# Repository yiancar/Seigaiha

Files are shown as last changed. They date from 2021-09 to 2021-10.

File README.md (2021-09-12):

Seigaiha
================

seigaiha

This Alice layout keyboard kit is made using ONLY through hole components and inspired by the [Plaid](https://github.com/hsgw/plaid) and [TGR Alice](https://geekhack.org/index.php?topic=95054.0).

Atmega328p with VUSB on [QMK firmware](https://github.com/qmk/qmk_firmware).

To alter the pcb use KiCAD V5.0 or newer as it already contains most of the libraries. The additional libraries are provided.

License
===========

This project is licensed under the [Creative Commons Attribution-NonCommercial 4.0 International License](https://creativecommons.org/licenses/by-nc/4.0/).

If you have remixed, adapted or build upon this work and wish to remove the non-commercial clause for your own project please contact me at https://www.yiancar-designs.com. Your request is more than likely to be granted. The non-commercial part of the license is intended to avoid direct copies of the work to be sold for commercial gain by third parties.

The USB4085-GF-A footprint, symbol and 3D model are licensed under [Attribution-ShareAlike 4.0 International](https://creativecommons.org/licenses/by-sa/4.0/). Originally created by [SnapEDA](https://snapeda.com). The footprint has been modified to increase the hole size of the shield pads.



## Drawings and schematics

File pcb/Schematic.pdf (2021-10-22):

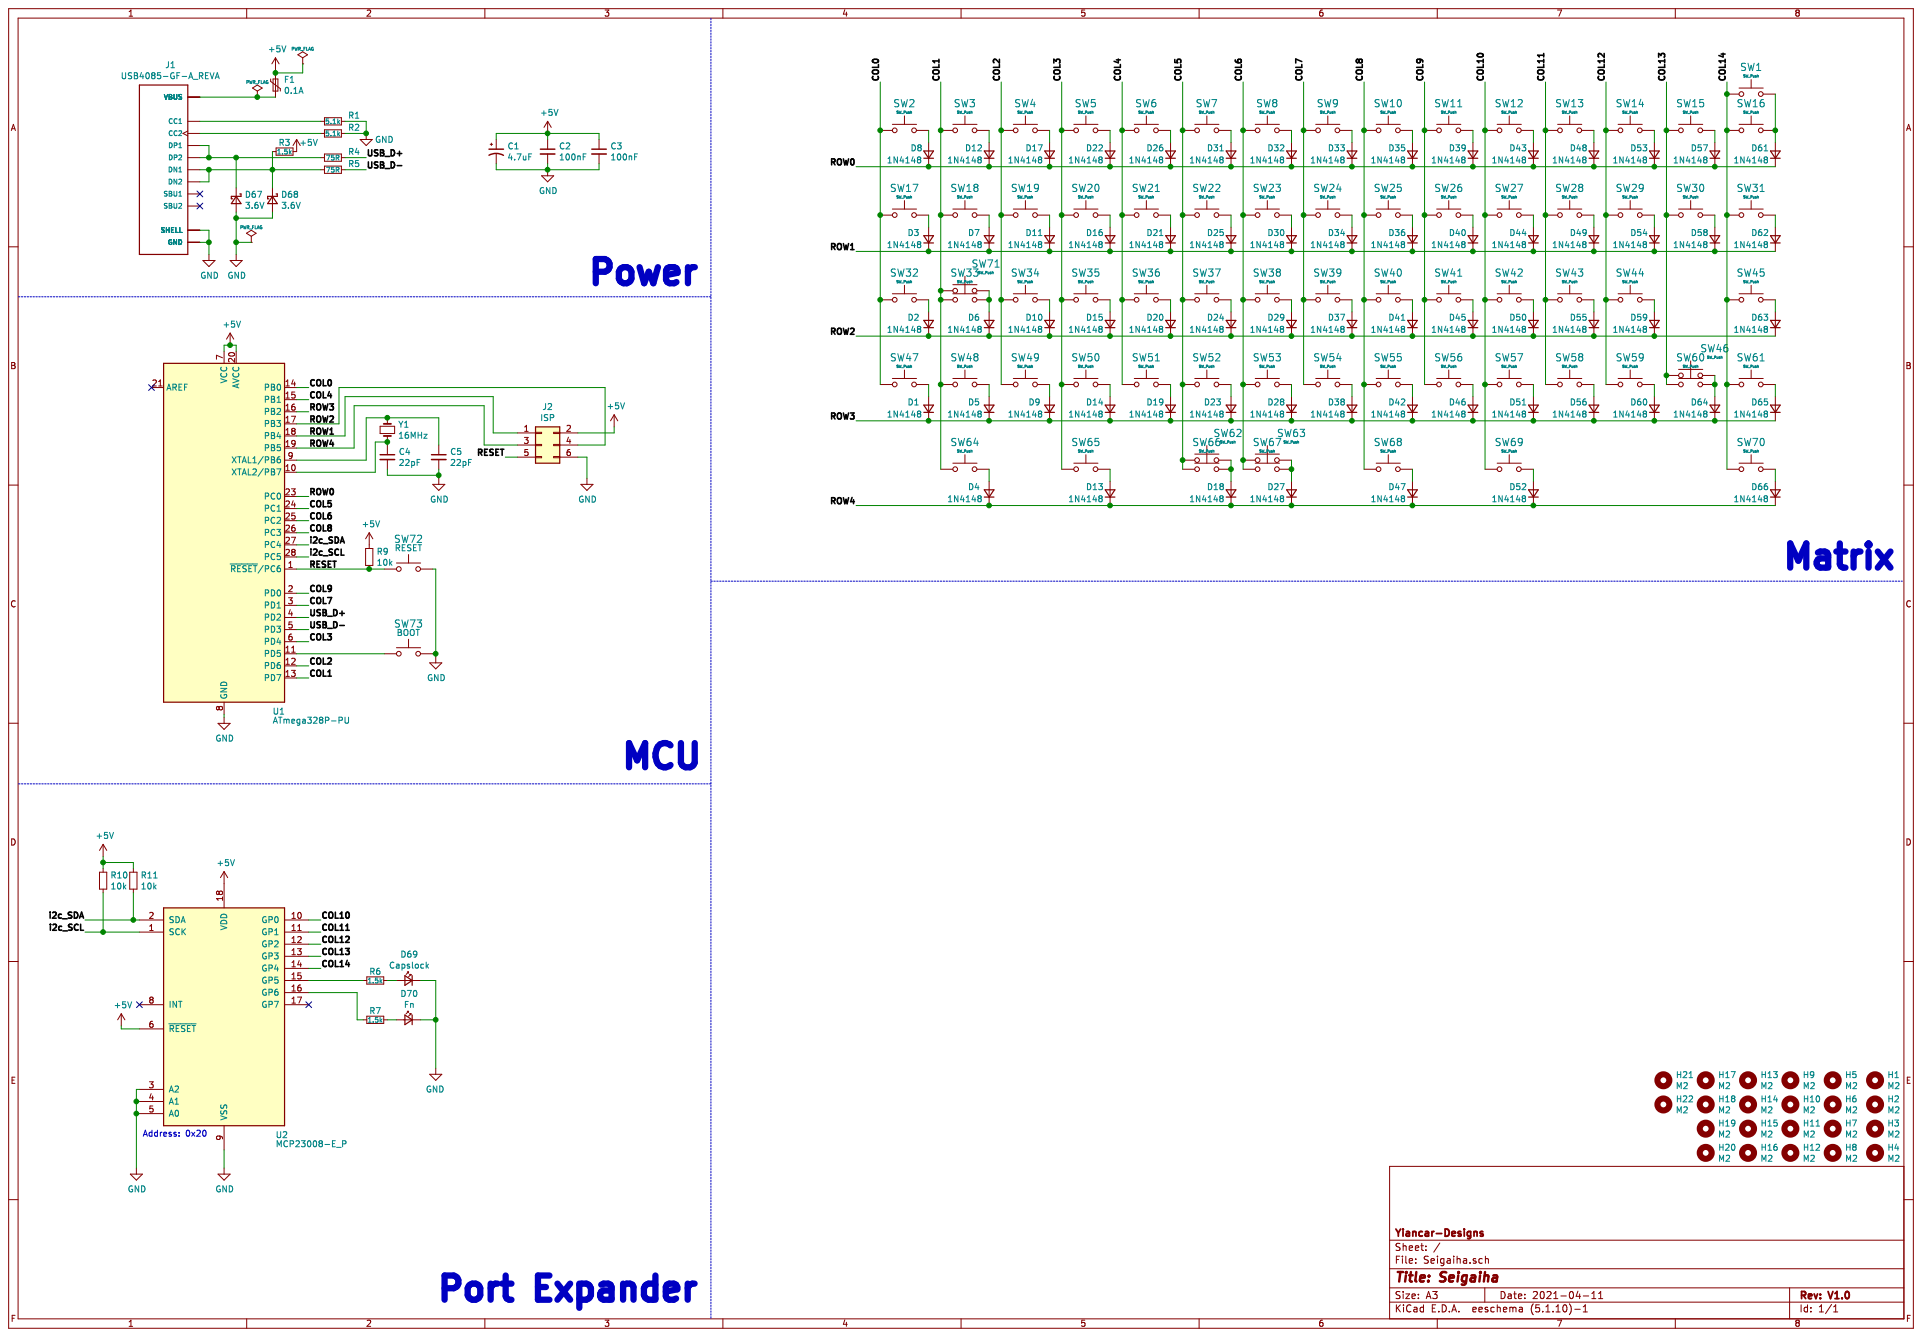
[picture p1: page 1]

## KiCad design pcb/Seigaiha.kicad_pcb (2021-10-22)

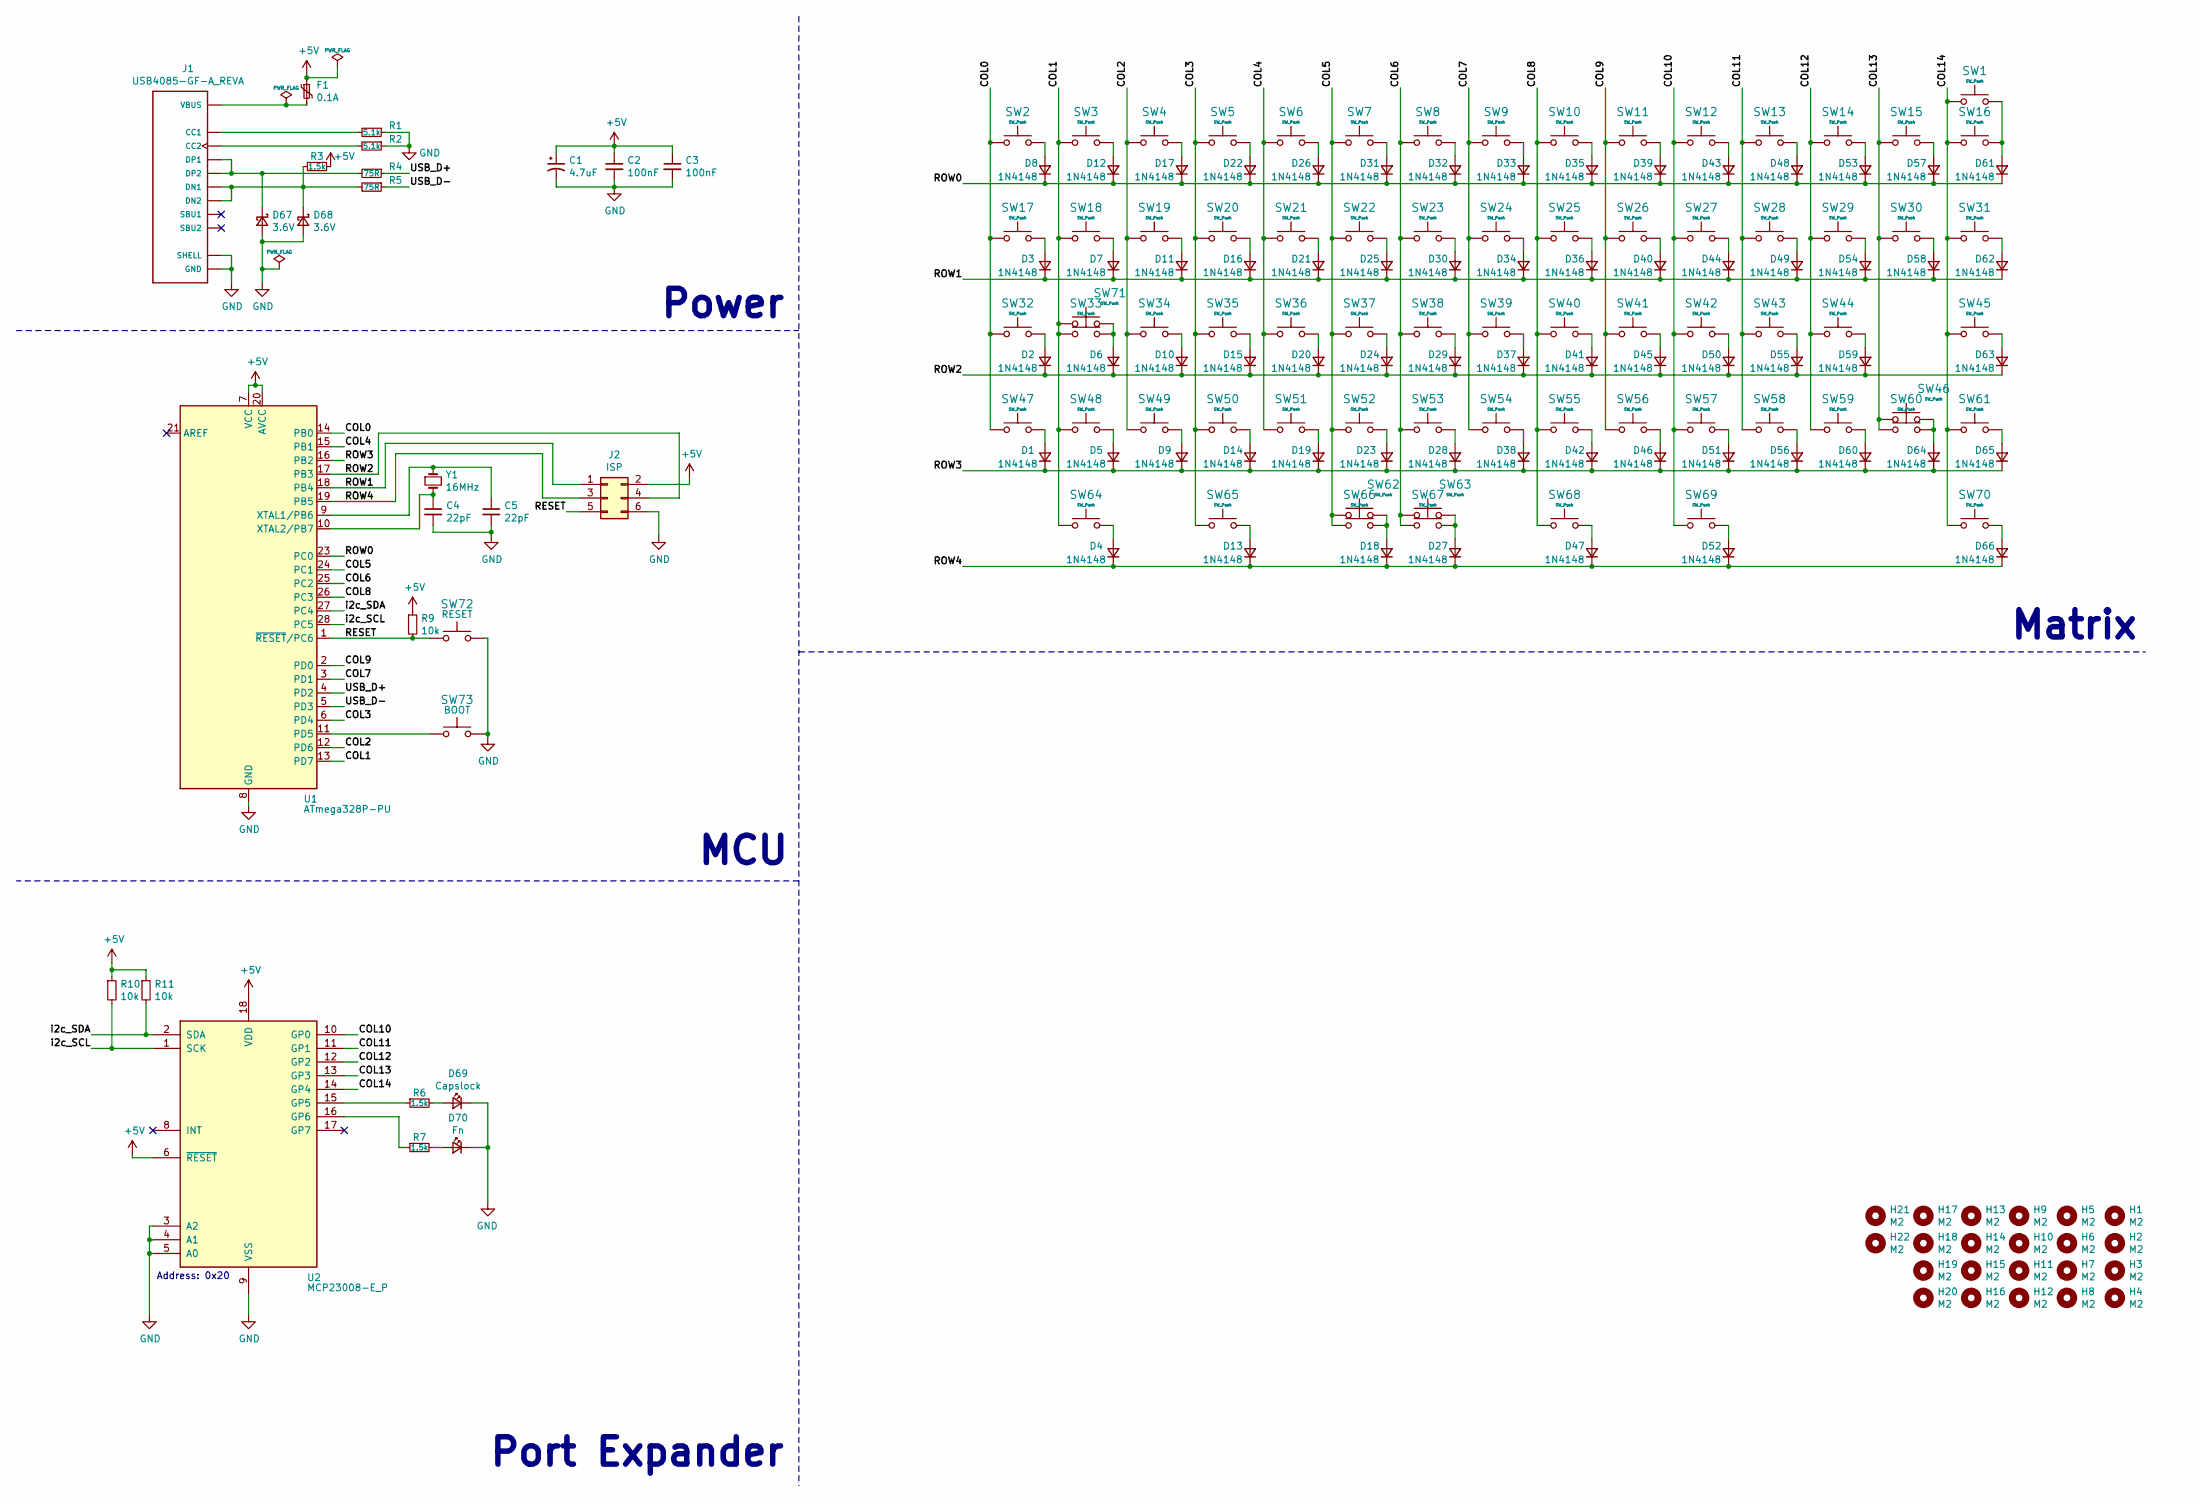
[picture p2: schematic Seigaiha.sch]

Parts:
C1: 4.7uF; CP_Radial_D4.0mm_P1.50mm
C2, C3: 100nF; C_Disc_D4.3mm_W1.9mm_P5.00mm
C4, C5: 22pF; C_Disc_D4.3mm_W1.9mm_P5.00mm
D1, D2, D3, D4, D5, D6, D7, D8, D9, D10, D11, D12, D13, D14, D15, D16, D17, D18, D19, D20, D21, D22, D23, D24, D25, D26, D27, D28, D29, D30, D31, D32, D33, D34, D35, D36, D37, D38, D39, D40, D41, D42, D43, D44, D45, D46, D47, D48, D49, D50, D51, D52, D53, D54, D55, D56, D57, D58, D59, D60, D61, D62, D63, D64, D65, D66: 1N4148; D_DO-35_SOD27_P7.62mm_Horizontal
D67, D68: 3.6V; D_DO-35_SOD27_P7.62mm_Horizontal
D69: Capslock; LED_D3.0mm_Clear
D70: Fn; LED_D3.0mm_Clear
F1: 0.1A; C_Disc_D5.0mm_W2.5mm_P5.00mm
H1, H2, H3, H4, H5, H6, H7, H8, H9, H10, H11, H12, H13, H14, H15, H16, H17, H18, H19, H20, H21, H22: M2; MountingHole_2.2mm_M2_DIN965_Pad
J1: USB4085-GF-A_REVA; GCT_USB4085-GF-A_REVA
J2: ISP; PinHeader_2x03_P2.54mm_Vertical
R1, R2: 5.1k; R_Axial_DIN0204_L3.6mm_D1.6mm_P5.08mm_Horizontal
R3, R6, R7: 1.5k; R_Axial_DIN0204_L3.6mm_D1.6mm_P5.08mm_Horizontal
R4, R5: 75R; R_Axial_DIN0204_L3.6mm_D1.6mm_P5.08mm_Horizontal
R9, R10, R11: 10k; R_Axial_DIN0204_L3.6mm_D1.6mm_P5.08mm_Horizontal
SW1, SW2, SW3, SW4, SW5, SW6, SW7, SW8, SW9, SW10, SW11, SW12, SW13, SW14, SW15, SW17, SW19, SW20, SW21, SW22, SW23, SW24, SW25, SW26, SW27, SW28, SW29, SW30, SW32, SW34, SW35, SW36, SW37, SW38, SW39, SW40, SW41, SW42, SW43, SW44, SW47, SW49, SW50, SW51, SW52, SW53, SW54, SW55, SW56, SW57, SW58, SW59, SW61, SW67: SW_Push; MX-1U-NoLED
SW16: SW_Push; MX-2U-NoLED
SW18, SW31, SW64, SW65, SW69, SW70: SW_Push; MX-1.5U-NoLED
SW33, SW46: SW_Push; MX-1.75U-NoLED
SW45, SW62: SW_Push; MX-2.25U-ReversedStabilizers-NoLED
SW48: SW_Push; MX-2.25U-NoLED
SW60: SW_Push; MX-2.75U-NoLED
SW63, SW71: SW_Push; MX-1.25U-NoLED
SW66: SW_Push; MX-2U-ReversedStabilizers-NoLED
SW68: SW_Push; MX-2.75U-ReversedStabilizers-NoLED
SW72: RESET; SW_PUSH_6mm
SW73: BOOT; SW_PUSH_6mm
U1: ATmega328P-PU; DIP-28_W7.62mm
U2: MCP23008-E_P; DIP-18_W7.62mm
Y1: 16MHz; Crystal_HC49-4H_Vertical

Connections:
+5V: C1.1, C2.1, C3.1, F1.1, J2.2, R3.1, R9.1, R10.1, R11.1, U1.7 (VCC), U1.20 (AVCC), U2.6 (~RESET~), U2.18 (VDD)
/COL0: SW2.2, SW17.2, SW32.2, SW47.2, U1.14 (PB0)
/COL1: SW3.2, SW18.2, SW33.2, SW48.2, SW64.2, SW71.2, U1.13 (PD7)
/COL2: SW4.2, SW19.2, SW34.2, SW49.2, U1.12 (PD6)
/COL3: SW5.2, SW20.2, SW35.2, SW50.2, SW65.2, U1.6 (PD4)
/COL4: SW6.2, SW21.2, SW36.2, SW51.2, U1.15 (PB1)
/COL5: SW7.2, SW22.2, SW37.2, SW52.2, SW62.2, SW66.2, U1.24 (PC1)
/COL6: SW8.2, SW23.2, SW38.2, SW53.2, SW63.2, SW67.2, U1.25 (PC2)
/COL7: SW9.1, SW24.1, SW39.1, SW54.1, U1.3 (PD1)
/COL8: SW10.1, SW25.1, SW40.1, SW55.1, SW68.1, U1.26 (PC3)
/COL9: SW11.1, SW26.1, SW41.1, SW56.1, U1.2 (PD0)
/COL10: SW12.1, SW27.1, SW42.1, SW57.1, SW69.1, U2.10 (GP0)
/COL11: SW13.1, SW28.1, SW43.1, SW58.1, U2.11 (GP1)
/COL12: SW14.1, SW29.1, SW44.1, SW59.1, U2.12 (GP2)
/COL13: SW15.1, SW30.1, SW46.1, SW60.1, U2.13 (GP3)
/COL14: SW1.1, SW16.1, SW31.1, SW45.1, SW61.1, SW70.1, U2.14 (GP4)
/RESET: J2.5, R9.2, SW72.2, U1.1 (~RESET~/PC6)
/ROW0: D8.1 (K), D12.1 (K), D17.1 (K), D22.1 (K), D26.1 (K), D31.1 (K), D32.1 (K), D33.1 (K), D35.1 (K), D39.1 (K), D43.1 (K), D48.1 (K), D53.1 (K), D57.1 (K), D61.1 (K), U1.23 (PC0)
/ROW1: D3.1 (K), D7.1 (K), D11.1 (K), D16.1 (K), D21.1 (K), D25.1 (K), D30.1 (K), D34.1 (K), D36.1 (K), D40.1 (K), D44.1 (K), D49.1 (K), D54.1 (K), D58.1 (K), D62.1 (K), J2.1, U1.18 (PB4)
/ROW2: D2.1 (K), D6.1 (K), D10.1 (K), D15.1 (K), D20.1 (K), D24.1 (K), D29.1 (K), D37.1 (K), D41.1 (K), D45.1 (K), D50.1 (K), D55.1 (K), D59.1 (K), D63.1 (K), J2.4, U1.17 (PB3)
/ROW3: D1.1 (K), D5.1 (K), D9.1 (K), D14.1 (K), D19.1 (K), D23.1 (K), D28.1 (K), D38.1 (K), D42.1 (K), D46.1 (K), D51.1 (K), D56.1 (K), D60.1 (K), D64.1 (K), D65.1 (K), U1.16 (PB2)
/ROW4: D4.1 (K), D13.1 (K), D18.1 (K), D27.1 (K), D47.1 (K), D52.1 (K), D66.1 (K), J2.3, U1.19 (PB5)
/USB_D+: R4.1, U1.4 (PD2)
/USB_D-: R5.1, U1.5 (PD3)
/i2c_SCL: R10.2, U1.28 (PC5), U2.1 (SCK)
/i2c_SDA: R11.2, U1.27 (PC4), U2.2 (SDA)
GND: C1.2, C2.2, C3.2, C4.2, C5.2, D67.2 (A), D68.2 (A), D69.1 (K), D70.1 (K), J1.A1 (GND), J1.A12 (GND), J1.B1 (GND), J1.B12 (GND), J1.P1 (SHELL), J1.P2 (SHELL), J1.P3 (SHELL), J1.P4 (SHELL), J2.6, R1.1, R2.1, SW72.1, SW73.1, U1.8 (GND), U1.22 (GND), U2.3 (A2), U2.4 (A1), U2.5 (A0), U2.9 (VSS)
unnamed: C4.1, U1.10 (XTAL2/PB7), Y1.2
unnamed: C5.1, U1.9 (XTAL1/PB6), Y1.1
unnamed: D1.2 (A), SW47.1
unnamed: D2.2 (A), SW32.1
unnamed: D3.2 (A), SW17.1
unnamed: D4.2 (A), SW64.1
unnamed: D5.2 (A), SW48.1
unnamed: D6.2 (A), SW33.1, SW71.1
unnamed: D7.2 (A), SW18.1
unnamed: D8.2 (A), SW2.1
unnamed: D9.2 (A), SW49.1
unnamed: D10.2 (A), SW34.1
unnamed: D11.2 (A), SW19.1
unnamed: D12.2 (A), SW3.1
unnamed: D13.2 (A), SW65.1
unnamed: D14.2 (A), SW50.1
unnamed: D15.2 (A), SW35.1
unnamed: D16.2 (A), SW20.1
unnamed: D17.2 (A), SW4.1
unnamed: D18.2 (A), SW62.1, SW66.1
unnamed: D19.2 (A), SW51.1
unnamed: D20.2 (A), SW36.1
unnamed: D21.2 (A), SW21.1
unnamed: D22.2 (A), SW5.1
unnamed: D23.2 (A), SW52.1
unnamed: D24.2 (A), SW37.1
unnamed: D25.2 (A), SW22.1
unnamed: D26.2 (A), SW6.1
unnamed: D27.2 (A), SW63.1, SW67.1
unnamed: D28.2 (A), SW53.1
unnamed: D29.2 (A), SW38.1
unnamed: D30.2 (A), SW23.1
unnamed: D31.2 (A), SW7.1
unnamed: D32.2 (A), SW8.1
unnamed: D33.2 (A), SW9.2
unnamed: D34.2 (A), SW24.2
unnamed: D35.2 (A), SW10.2
unnamed: D36.2 (A), SW25.2
unnamed: D37.2 (A), SW39.2
unnamed: D38.2 (A), SW54.2
unnamed: D39.2 (A), SW11.2
unnamed: D40.2 (A), SW26.2
unnamed: D41.2 (A), SW40.2
unnamed: D42.2 (A), SW55.2
unnamed: D43.2 (A), SW12.2
unnamed: D44.2 (A), SW27.2
unnamed: D45.2 (A), SW41.2
unnamed: D46.2 (A), SW56.2
unnamed: D47.2 (A), SW68.2
unnamed: D48.2 (A), SW13.2
unnamed: D49.2 (A), SW28.2
unnamed: D50.2 (A), SW42.2
unnamed: D51.2 (A), SW57.2
unnamed: D52.2 (A), SW69.2
unnamed: D53.2 (A), SW14.2
unnamed: D54.2 (A), SW29.2
unnamed: D55.2 (A), SW43.2
unnamed: D56.2 (A), SW58.2
unnamed: D57.2 (A), SW15.2
unnamed: D58.2 (A), SW30.2
unnamed: D59.2 (A), SW44.2
unnamed: D60.2 (A), SW59.2
unnamed: D61.2 (A), SW1.2, SW16.2
unnamed: D62.2 (A), SW31.2
unnamed: D63.2 (A), SW45.2
unnamed: D64.2 (A), SW46.2, SW60.2
unnamed: D65.2 (A), SW61.2
unnamed: D66.2 (A), SW70.2
unnamed: D67.1 (K), J1.A6 (DP1), J1.B6 (DP2), R4.2
unnamed: D68.1 (K), J1.A7 (DN1), J1.B7 (DN2), R3.2, R5.2
unnamed: D69.2 (A), R6.2
unnamed: D70.2 (A), R7.2
unnamed: F1.2, J1.A4 (VBUS), J1.A9 (VBUS), J1.B4 (VBUS), J1.B9 (VBUS)
unnamed: J1.A5 (CC1), R1.2
unnamed: J1.B5 (CC2), R2.2
unnamed: R6.1, U2.15 (GP5)
unnamed: R7.1, U2.16 (GP6)
unnamed: SW73.2, U1.11 (PD5)

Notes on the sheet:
Address: 0x20
Power
MCU
Port Expander
Matrix

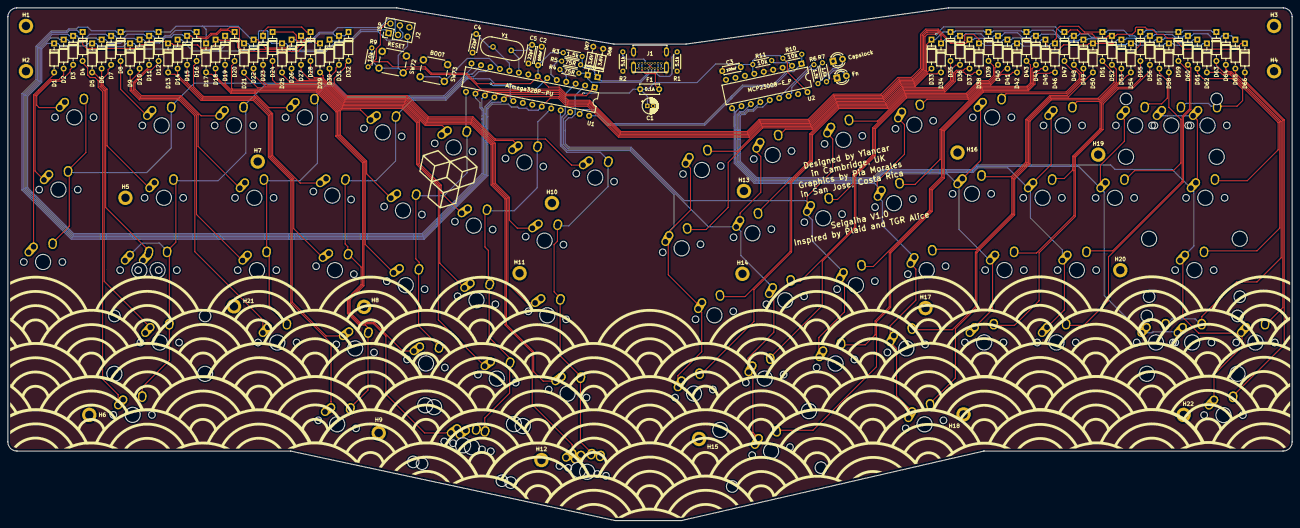
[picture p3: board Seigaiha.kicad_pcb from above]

Board: 2 copper layers, 338.1 x 135.0 mm, 187 parts (0 on the bottom side), 105 nets.

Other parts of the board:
Ref**: Val**; seigaiha_logo

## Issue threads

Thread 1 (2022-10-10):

Creating the pcb

slugb0t, 2022-10-10:
Hi I'm fairly new to custom keyboards but have been eyeing this pcb for my build. I'm wondering on how do I go about getting this design created for me? Are there any recommended companies to go through or sites that provide services for this? If so is just providing them the GitHub link or what is required for creating this into a PCB?

Any help is appreciated, thank you!

yiancar, 2022-10-10:
Hello @slugb0t.

I will answer by saying you can buy our kit with all the components as well as with building instructions:)
https://mykeyboard.eu/catalogue/seigaiha-kit_4821/
https://novelkeys.com/products/seigaiha-keyboard-kit
https://mechboards.co.uk/products/seigaiha-kit

In case you still want to manufacture this for your own personal use, the files must be opened with KiCAD, you need to exports the gerbers and then send them to a PCB manufacturer. Also you would need all the components and program the MCU with the bootloader.

I hope this helps!
Cheers,
Yiangos

slugb0t, 2022-10-17:
Thank you @yiancar for providing the links! I had been on novelkeys but they haven't been in stock in a while now so I was trying to find other places! Went with mechboards and even though they reside in the UK I got my package within the week. Thanks for designing a cool looking board! Excited to create my build with this!

yiancar, 2022-10-17:
Cheers:) We are trying to ship some more stock to NK in the next months:)

Closed 2022-10-10.

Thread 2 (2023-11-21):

Acrylic cover and screws

forggy0113, 2023-11-21:
Hi, Yiangos

Recently I want to make a seigaiha keyboard, and I was looking for CAD file for the acrylic cover for this build, but sadly I couldn't find any.

And second question is, what is the length of M2 screws and the standoffs.

I’m looking forward to your reply.

Best regard,

hungngodev, 2024-12-08:
I'm also very excited in this

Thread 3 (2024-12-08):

3d printed case

hungngodev, 2024-12-08:
Hi, I just ordered my seigaiha from NK. I would love if you can share the stl file for the 3d printed case. Thank you so much!!
https://www.reddit.com/r/MechanicalKeyboards/comments/q8ya8u/not_the_prettiest_photo_but_my_first_custom_3d/

yiancar, 2024-12-08:
Hello I have not made the case therefore I cannot help

Closed 2024-12-08.

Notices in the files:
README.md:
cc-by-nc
